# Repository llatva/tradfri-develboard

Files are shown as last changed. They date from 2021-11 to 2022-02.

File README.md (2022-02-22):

# tradfri-develboard

Based on work by basilfx@github, see: https://github.com/basilfx/TRADFRI-Hacking

**LICENSE**

Creative Commons BY Attribution 4.0 International

**DISCLAIMER**

This repository is provided "AS IS", without warranty of any kind, express or implied.
This content is not affiliated with IKEA of Sweden AB. Use the information on your own risk.

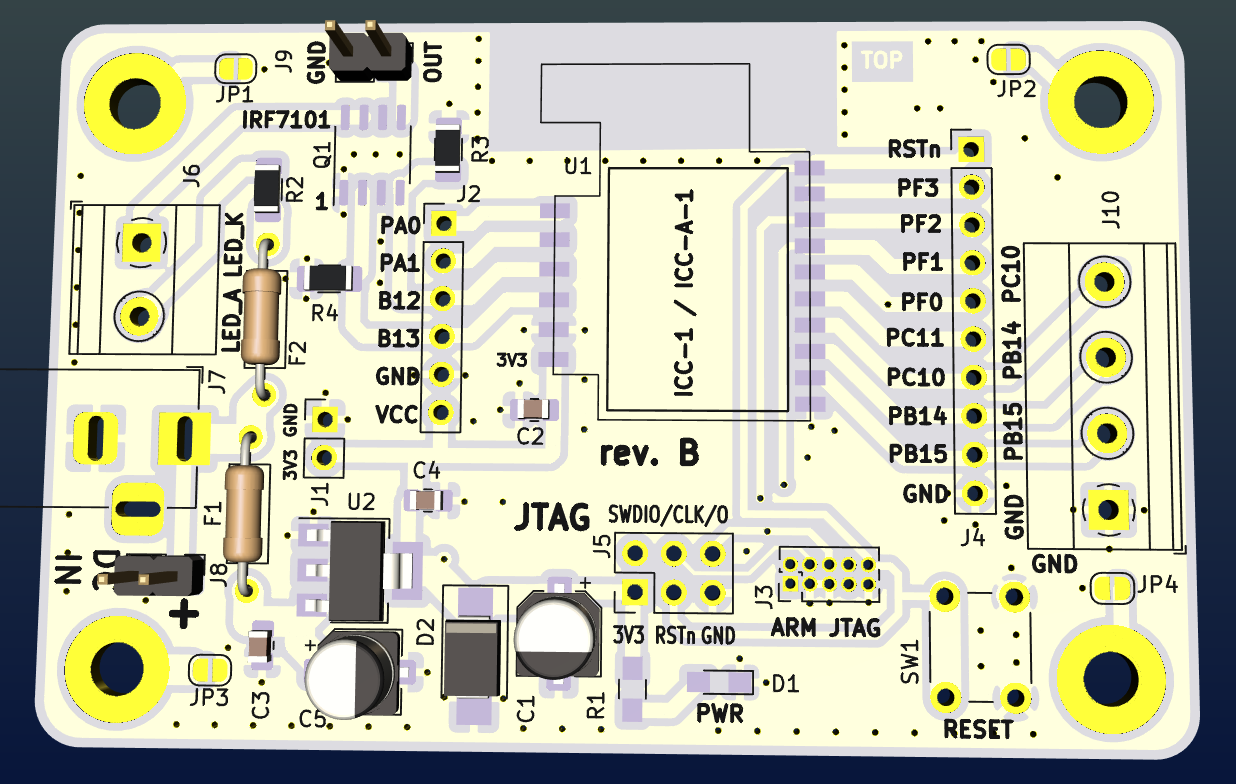
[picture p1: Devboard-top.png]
Preview


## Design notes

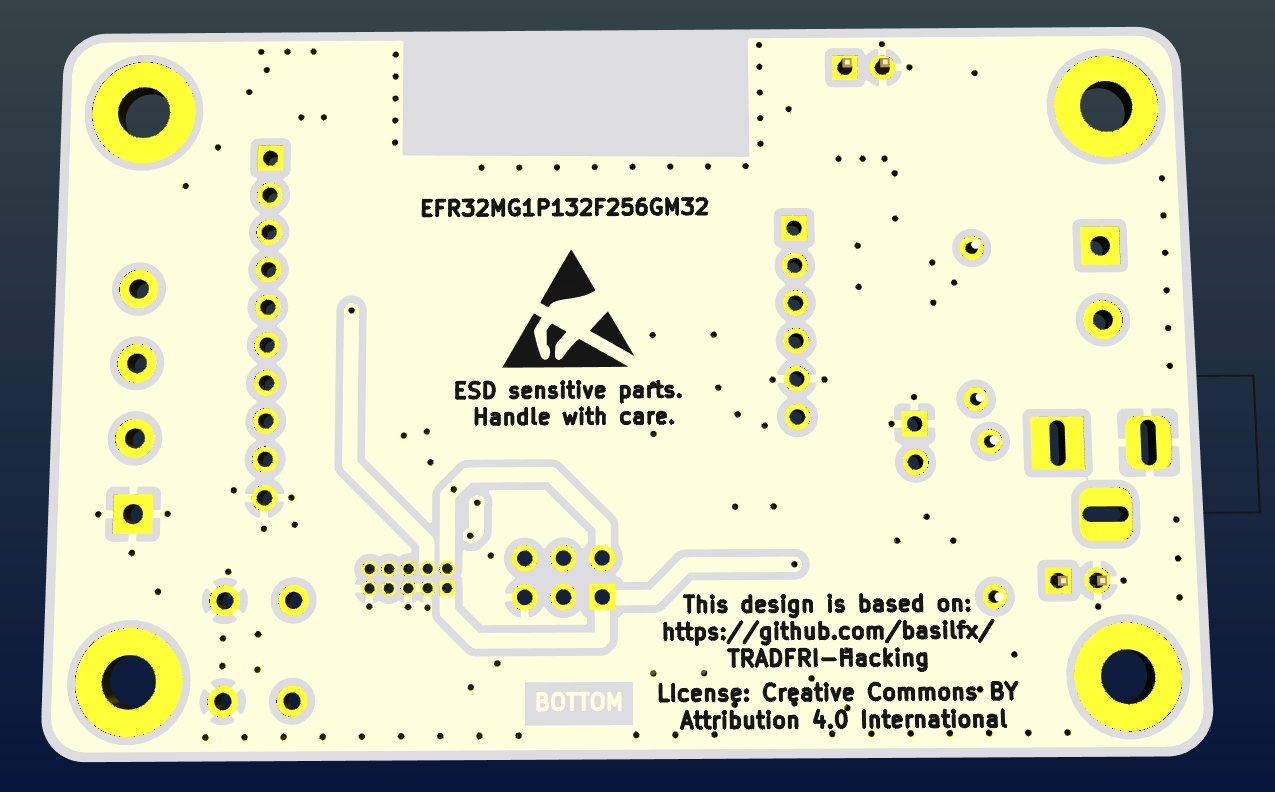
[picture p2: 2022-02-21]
Devboard-bottom.png

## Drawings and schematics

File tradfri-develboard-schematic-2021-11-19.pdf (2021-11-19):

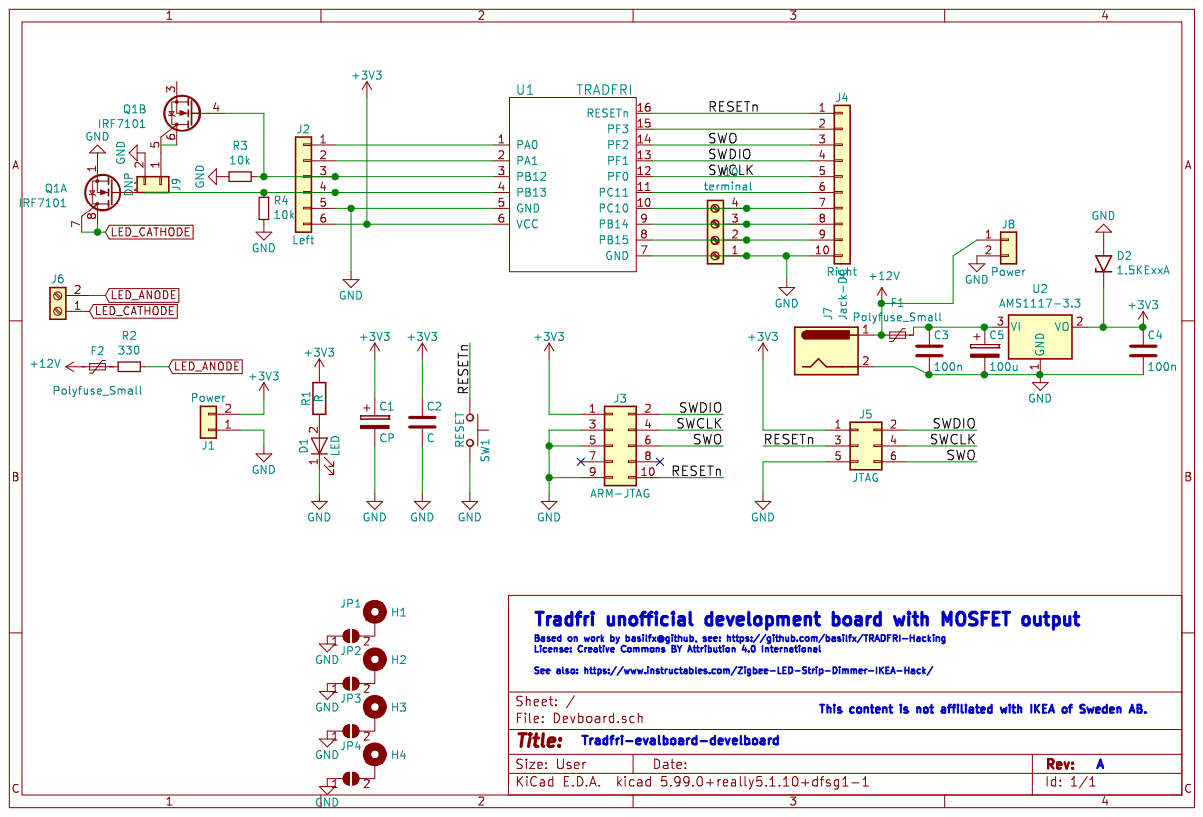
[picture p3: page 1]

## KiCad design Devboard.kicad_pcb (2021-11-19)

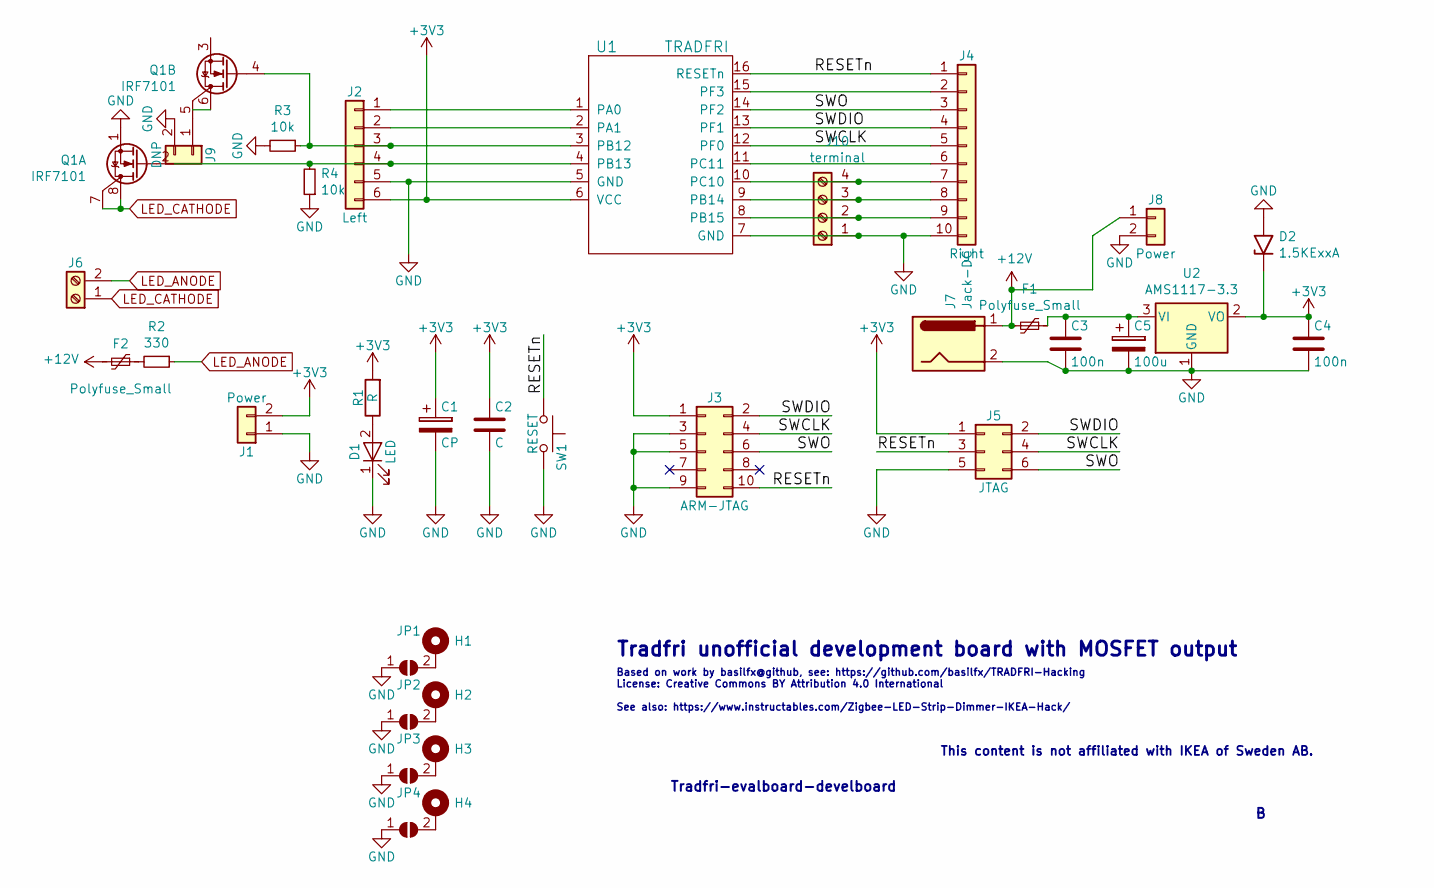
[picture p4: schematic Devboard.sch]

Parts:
C1: CP; CP_Elec_5x5.4
C2: C; C_0805_2012Metric_Pad1.18x1.45mm_HandSolder
C3, C4: 100n; C_0805_2012Metric_Pad1.18x1.45mm_HandSolder
C5: 100u; CP_Elec_5x5.4
D1: LED; LED_0805_HandSoldering
D2: 1.5KExxA; D_SMB_Handsoldering
F1, F2: Polyfuse_Small; R_Axial_DIN0207_L6.3mm_D2.5mm_P10.16mm_Horizontal
H1, H2, H3, H4: MountingHole_Pad; MountingHole_3.5mm_Pad_TopBottom
J1: Power; Pin_Header_Straight_1x02_Pitch2.54mm
J2: Left; Pin_Header_Straight_1x06_Pitch2.54mm
J3: ARM-JTAG; Pin_Header_Straight_2x05_Pitch1.27mm
J4: Right; Pin_Header_Straight_1x10_Pitch2.54mm
J5: JTAG; Pin_Header_Straight_2x03_Pitch2.54mm
J6: Screw_Terminal_01x02; TerminalBlock_Phoenix_MKDS-1,5-2_1x02_P5.00mm_Horizontal
J7: Jack-DC; BarrelJack_Horizontal
J8: Power; PinHeader_1x02_P2.54mm_Vertical
J9: DNP; PinHeader_1x02_P2.54mm_Vertical
J10: terminal; TerminalBlock_Phoenix_MKDS-1,5-4_1x04_P5.00mm_Horizontal
JP1, JP2, JP3, JP4: SolderJumper_2_Open; SolderJumper-2_P1.3mm_Open_RoundedPad1.0x1.5mm
Q1: IRF7101; SO-8_3.9x4.9mm_P1.27mm
R1: R; R_0805_HandSoldering
R2: 330; R_1206_3216Metric_Pad1.30x1.75mm_HandSolder
R3, R4: 10k; R_1206_3216Metric_Pad1.30x1.75mm_HandSolder
SW1: RESET; SW_PUSH_6mm
U1: TRADFRI; TRADFRI_PCB2.0
U2: AMS1117-3.3; SOT-223-3_TabPin2

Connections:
+3V3: C1.1, C2.1, C4.1, D2.1 (A1), J1.2, J2.6, J3.1, J5.1, R1.2, U1.6 (VCC), U2.2 (VO)
+12V: F1.2, F2.2, J7.1, J8.1
/RESETn: J3.10, J4.1, J5.3, SW1.1, U1.16 (RESETn)
/SWCLK: J3.4, J4.5, J5.4, U1.12 (PF0)
/SWDIO: J3.2, J4.4, J5.2, U1.13 (PF1)
/SWO: J3.6, J4.3, J5.6, U1.14 (PF2)
GND: C1.2, C2.2, C3.2, C4.2, C5.2, D1.1 (K), D2.2 (A2), J1.1, J2.5, J3.3, J3.5, J3.9, J4.10, J5.5, J7.2, J8.2, J9.2, J10.1, JP1.1 (A), JP2.1 (A), JP3.1 (A), JP4.1 (A), Q1.1 (S2), R3.2, R4.1, SW1.2, U1.5 (GND), U1.7 (GND), U2.1 (GND)
LED_ANODE: J6.2, R2.1
LED_CATHODE: J6.1, Q1.7 (D2), Q1.8 (D2)
unnamed: C3.1, C5.1, F1.1, U2.3 (VI)
unnamed: D1.2 (A), R1.1
unnamed: F2.1, R2.2
unnamed: H1.1, JP1.2 (B)
unnamed: H2.1, JP2.2 (B)
unnamed: H3.1, JP3.2 (B)
unnamed: H4.1, JP4.2 (B)
unnamed: J2.1, U1.1 (PA0)
unnamed: J2.2, U1.2 (PA1)
unnamed: J2.3, Q1.4 (G2), R3.1, U1.3 (PB12)
unnamed: J2.4, Q1.2 (G1), R4.2, U1.4 (PB13)
unnamed: J4.2, U1.15 (PF3)
unnamed: J4.6, U1.11 (PC11)
unnamed: J9.1, Q1.5 (D2)
unnamed: J4.9, J10.2, U1.8 (PB15)
unnamed: J4.8, J10.3, U1.9 (PB14)
unnamed: J4.7, J10.4, U1.10 (PC10)

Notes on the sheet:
Based on work by basilfx@github, see: https://github.com/basilfx/TRADFRI-Hacking License: Creative Commons BY Attribution 4.0 International See also: https://www.instructables.com/Zigbee-LED-Strip-Dimmer-IKEA-Hack/
Tradfri unofficial development board with MOSFET output
Tradfri-evalboard-develboard
This content is not affiliated with IKEA of Sweden AB.

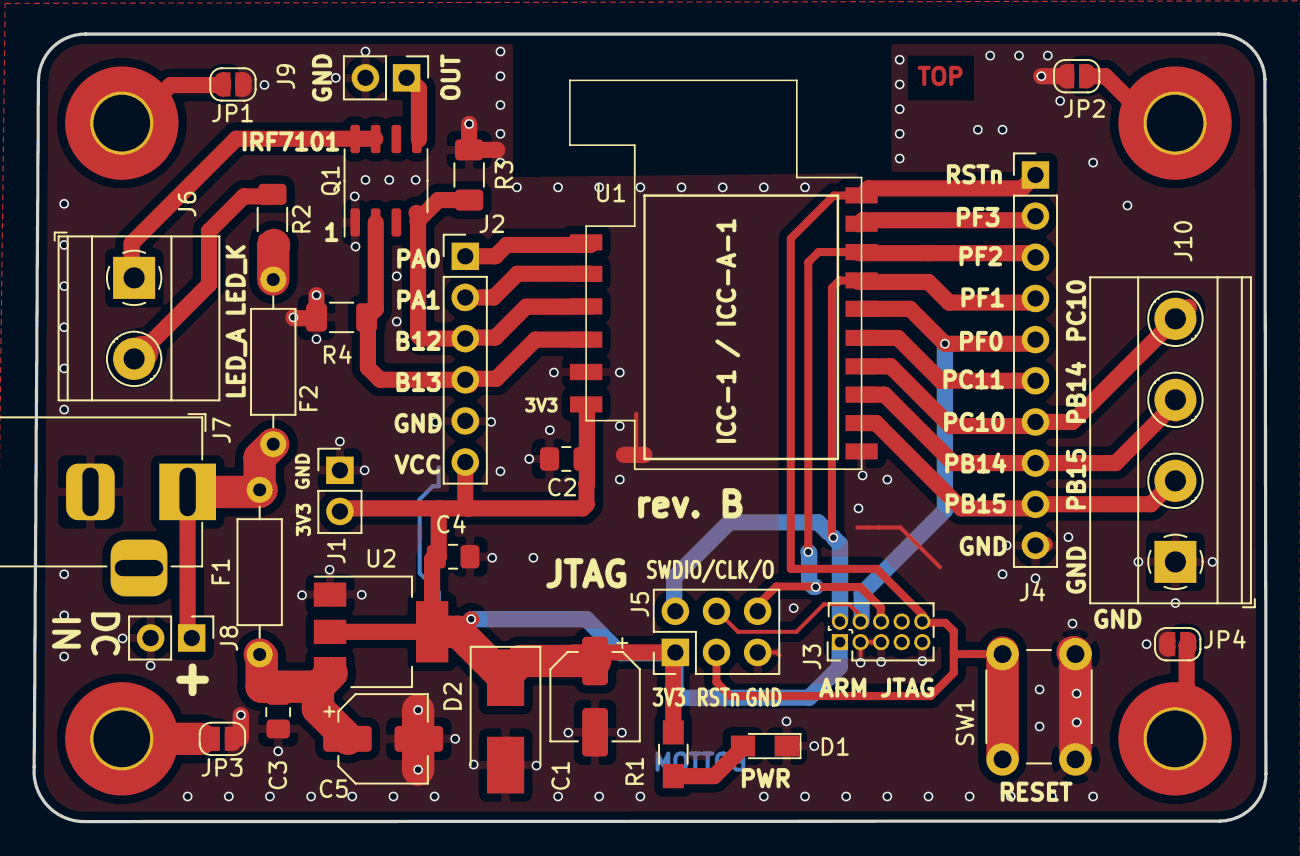
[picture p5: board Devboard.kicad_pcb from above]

Board: 2 copper layers, 76.0 x 48.6 mm, 35 parts (0 on the bottom side), 26 nets.

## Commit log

2021-11-19 revision A to github
    [Devboard-B_Cu.gbl, Devboard-B_Mask.gbs, Devboard-B_Paste.gbp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]
2021-11-19 schematic texts and minor stylishing
    [Devboard.sch]
2021-11-19 schamatic printout
2021-11-19 enhancements to pcb, this will be possible rev B
    [Devboard.kicad_pcb, Devboard.sch]
2022-02-22 remove old gerbers
    [Devboard-B_Cu.gbl, Devboard-B_Mask.gbs, Devboard-B_Paste.gbp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]
